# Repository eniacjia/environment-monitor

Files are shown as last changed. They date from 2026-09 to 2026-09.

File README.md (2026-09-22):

# DJIA Environmental Monitor

A compact environmental monitor built with an Arduino Uno, a 2.4-inch
MCUFRIEND TFT touchscreen shield, a BME280 sensor, and a DHT11 humidity module.
The device displays temperature and atmospheric pressure as large live readings
or rolling one-hour, eight-hour, and 24-hour charts, with live humidity.

> Local climate at a glance

Built by **DJIA using Codex**. The startup page generates `BUILD# YYYYMMDD`
automatically from the latest firmware compilation date.

## Features

- 2.4-inch 240 x 320 colour touchscreen
- BME280 temperature and pressure readings every 10 seconds
- DHT11 relative-humidity readings every 10 seconds
- Independent display mode for temperature, pressure, and humidity:
  - large current value
  - one-hour chart
  - eight-hour chart
  - 24-hour chart
- Automatic vertical chart scaling
- Touch the centre target to rotate the screen 90 degrees clockwise
- Portrait and landscape layouts
- Three-section dashboard: temperature, pressure, and humidity
- Ten-second branded startup page with large, centred title, tagline, build
  number, and attribution

## Project contents

| Path | Purpose |
|---|---|
| `firmware/EnvironmentMonitor/EnvironmentMonitor.ino` | Arduino source code |
| `firmware/release/` | Compiled Uno firmware files |
| `hardware/HARDWARE.md` | Wiring, pin use, and bill of materials |
| `docs/USER_GUIDE.md` | Operating instructions |
| `docs/FIRMWARE.md` | Firmware design and build instructions |
| `docs/TROUBLESHOOTING.md` | Diagnostic guidance |

## Quick start

1. Keep the TFT shield mounted on the Arduino Uno.
2. Keep the shield's microSD slot empty.
3. Connect BME280 `SDA` to `D11` and `SCL` to `D13`.
4. Connect BME280 power to `3.3V` and ground to `GND`.
5. Connect DHT11 `DATA` to `A5`, power to `5V`, and ground to `GND`.
6. Upload the sketch for an `arduino:avr:uno` target.
7. After startup, tap any measurement section to change its mode.

See [hardware/HARDWARE.md](hardware/HARDWARE.md) before connecting power.

## Important limitations

- Chart data currently resides in RAM and is lost after reset or power failure.
- The microSD interface cannot be used because `D11` and `D13` are repurposed
  for software I2C.
- The TFT backlight is wired directly to power on this shield. Software
  brightness control requires a transistor/MOSFET hardware modification.

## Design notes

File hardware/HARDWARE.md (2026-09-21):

# Hardware configuration

## Bill of materials

- Arduino Uno or fully compatible ATmega328P board
- 2.4-inch MCUFRIEND-style TFT LCD shield with resistive touchscreen
- BME280 breakout module
- DHT11 humidity module
- Seven jumper wires
- USB cable or suitable regulated Uno power supply

## Detected hardware

| Component | Detected/configured value |
|---|---|
| Arduino | Arduino Uno, ATmega328P |
| TFT controller | ILI9341, ID `0x9341` |
| TFT resolution | 240 x 320 pixels |
| Touch technology | Four-wire, single-touch resistive |
| Environmental sensor | BME280, chip ID `0x60` |
| Supported sensor addresses | `0x76` and `0x77` |
| Humidity sensor | DHT11 on `A5` |

## BME280 wiring

The Uno hardware I2C pins cannot be used because the shield uses `A4` for LCD
reset. The firmware therefore implements software I2C.

| BME280 pin | Arduino Uno pin | Notes |
|---|---|---|
| `VIN` or `VCC` | `3.3V` | Safest supply for the sensor |
| `GND` | `GND` | Common ground |
| `SDA` or `SDI` | `D11` | Software-I2C data |
| `SCL` or `SCK` | `D13` | Software-I2C clock |

Leave `CS` and `SDO` unconnected for this configuration. Some breakout boards
require `CS` pulled high to select I2C mode; use the breakout manufacturer's
instructions if it is not already pulled up.

## DHT11 wiring

| DHT11 pin | Arduino Uno pin | Notes |
|---|---|---|
| `VCC` or `+` | `5V` | Most three-pin DHT11 modules support 3.3-5 V |
| `DATA`, `S`, or `OUT` | `A5` | Used as digital pin 19 |
| `GND` or `-` | `GND` | Common ground |

Three-pin modules normally contain the required pull-up resistor. For a bare
four-pin DHT11, add a 4.7-10 kOhm resistor between `DATA` and `VCC`.

## TFT and touchscreen pin use

| Pins | Function |
|---|---|
| `D2-D9` | TFT parallel data bus; `D8-D9` are shared with touch |
| `A0-A4` | TFT control; `A2-A3` are shared with touch |
| `D10-D13` | Normally connected to the microSD slot |
| `D0-D1` | USB serial and sketch upload |
| `A5` | DHT11 single-wire data |

Because the sensor uses `D11` and `D13`, do not insert a microSD card while this
firmware is running.

## Measured touchscreen calibration

```cpp
const int XP = 8, XM = A2, YP = A3, YM = 9;
const int TS_LEFT = 125, TS_RT = 903;
const int TS_TOP = 129, TS_BOT = 878;
```

These values were measured for the specific shield used during development.
Recalibrate if a replacement shield has inaccurate or reversed touch input.

## Power notes

- Start with the BME280 powered from the Uno's `3.3V` output.
- The bare BME280 chip is not 5 V tolerant.
- A breakout labelled `VIN` may include a 5 V regulator and level shifting, but
  this must be confirmed from that module's documentation or schematic.
- Do not power the TFT backlight directly from a GPIO pin.

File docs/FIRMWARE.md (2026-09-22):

# Firmware notes

## Target

- Board FQBN: `arduino:avr:uno`
- MCU: ATmega328P
- Serial upload port used during development: `COM13`
- TFT controller: ILI9341 (`0x9341`)
- BME280 chip ID: `0x60`
- DHT11 data pin: `A5` (digital pin 19)

## Arduino libraries

Install these libraries through Arduino Library Manager:

- `MCUFRIEND_kbv` 3.0.0 or compatible
- `Adafruit GFX Library`
- `TouchScreen`

The sketch contains its own small software-I2C/BME280 driver and DHT11 protocol
reader. Adafruit BME280, BMP280, and DHT libraries are not required.

## Build with Arduino CLI

```powershell
arduino-cli compile --fqbn arduino:avr:uno firmware/EnvironmentMonitor
arduino-cli upload -p COM13 --fqbn arduino:avr:uno firmware/EnvironmentMonitor
```

Change `COM13` if the Uno appears on another port.

## Architecture

- `beginBMP280()` probes `0x76` and `0x77`, verifies BME280 ID `0x60`, loads
  temperature/pressure calibration coefficients, and configures normal mode.
- `readBMP280()` reads and compensates raw temperature and pressure values.
- `readDHT11()` performs the timed single-wire transaction, validates its
  checksum, and reports relative humidity.
- Software I2C uses open-drain-style pin switching on `D11/D13`.
- `collectHistory()` creates temperature and pressure averages, while
  `collectHumidityHistory()` creates equivalent DHT11 humidity averages. Each
  produces one-minute, eight-minute, and 24-minute history points from
  ten-second measurements.
- `drawPanel()` renders dynamically scaled history charts.
- `drawCurrentPanel()` renders centred, overprinted bold-style current values.
- `drawCurrentPanel()` also renders the dedicated light-green humidity section.
- `printBuildNumber()` converts the compiler-provided `__DATE__` value into the
  startup identifier `BUILD# YYYYMMDD` on every compile.
- `readTouch()` maps the measured resistive panel calibration for all four
  display rotations.

## RAM strategy

The Uno has only 2 KB of SRAM. Nine arrays of 60 signed 16-bit values retain
temperature, pressure, and humidity data for the one-hour, eight-hour, and
24-hour views. Values are stored in tenths of their displayed units. This
avoids storing thousands of individual ten-second samples.

## Persistence status

History is currently volatile. A future EEPROM implementation should use a
circular record layout, sequence counters, and checksums. Avoid rewriting a
single metadata byte every minute because ATmega328P EEPROM endurance is rated
at approximately 100,000 write/erase cycles per cell.

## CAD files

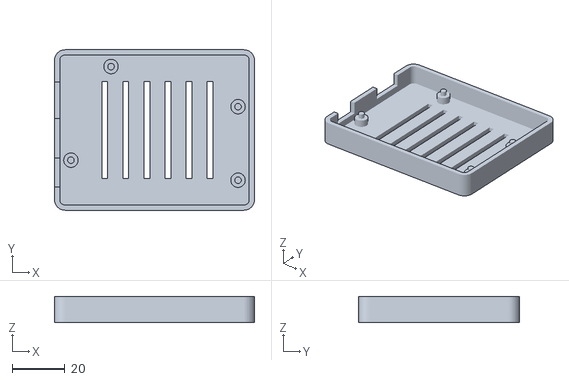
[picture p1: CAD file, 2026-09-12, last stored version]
enclosure/uno_24_tft_base.stl
76.0 x 61.0 x 10.0

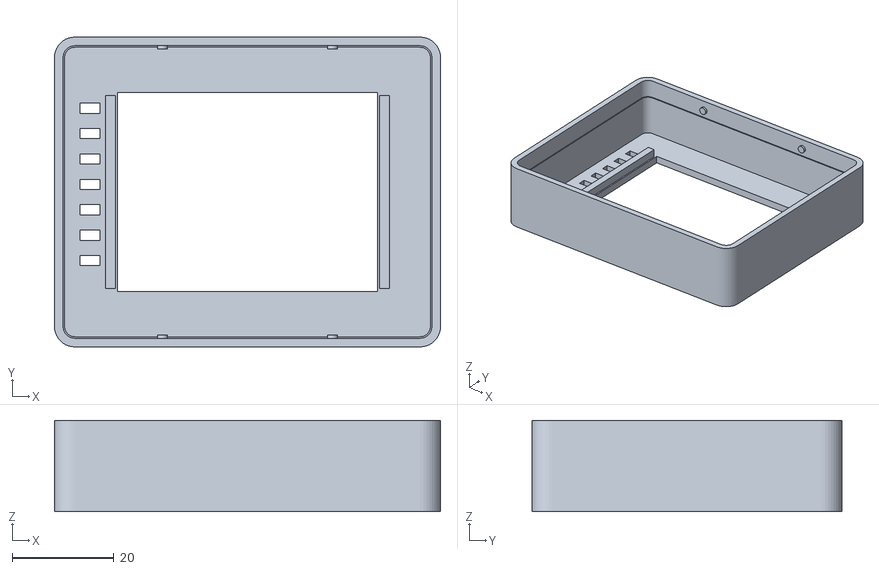
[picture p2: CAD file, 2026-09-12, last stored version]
enclosure/uno_24_tft_lid.stl
76.0 x 61.0 x 18.0

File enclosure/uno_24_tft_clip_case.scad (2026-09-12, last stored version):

/*
  Clip-on enclosure for Arduino Uno + common 2.4-inch MCUFRIEND TFT shield
  Designed for FDM printing. Units: millimetres.

  part = "print"     base and lid arranged for printing
  part = "base"      base only
  part = "lid"       lid only, bezel face down
  part = "assembly"  assembled preview
*/

$fn = 40;
part = "print";

// ---- Fit parameters: measure your particular shield before final printing ----
case_x = 76.0;
case_y = 61.0;
wall = 2.0;
corner_r = 4.0;
floor_t = 2.0;
base_h = 15.0;
lid_h = 18.0;
overlap = 5.0;
fit = 0.30;                 // per-side sliding clearance

uno_x = 68.6;
uno_y = 53.4;
board_x0 = (case_x - uno_x) / 2;
board_y0 = (case_y - uno_y) / 2;
standoff_h = 3.0;
standoff_od = 5.5;
standoff_pin = 2.5;

// Typical visible area for a 2.4-inch 240x320 module.
screen_x = 50.0;
screen_y = 38.0;
screen_center_x = case_x / 2;
screen_center_y = case_y / 2;
screen_clearance = 0.6;

// Connector locations measured from the lower-left outside corner.
usb_center_y = board_y0 + 38.0;
power_center_y = board_y0 + 10.5;

// Standard Uno mounting holes relative to the board lower-left corner.
uno_holes = [
  [2.54, 15.24],
  [17.78, 50.80],
  [66.04, 7.62],
  [66.04, 35.56]
];

module rounded_box(x, y, z, r) {
  linear_extrude(height=z)
    hull()
      for (px=[r, x-r], py=[r, y-r])
        translate([px, py]) circle(r=r);
}

module base_shell() {
  difference() {
    union() {
      rounded_box(case_x, case_y, base_h-overlap, corner_r);
      translate([wall, wall, base_h-overlap-0.2])
        rounded_box(case_x-2*wall, case_y-2*wall, overlap+0.2, corner_r-wall);
    }

    // Main electronics cavity.
    translate([wall, wall, floor_t])
      rounded_box(case_x-2*wall, case_y-2*wall, base_h+1, corner_r-wall);

    // USB type-B opening.
    translate([-1, usb_center_y-7.0, 5.0])
      cube([wall+3, 14.0, 12.0]);

    // DC barrel connector opening.
    translate([-1, power_center_y-5.5, 5.0])
      cube([wall+3, 11.0, 11.0]);

    // Snap pockets in the stepped rim.
    for (x=[case_x*0.28, case_x*0.72]) {
      translate([x-4, wall-1, base_h-3.2]) cube([8, wall+2, 2.0]);
      translate([x-4, case_y-wall-1, base_h-3.2]) cube([8, wall+2, 2.0]);
    }

    // Bottom ventilation.
    for (x=[18:8:58])
      translate([x, 12, -1]) cube([2.2, 37, floor_t+2]);
  }

  // Push-fit board supports. Pins can be clipped off for screw mounting.
  for (h=uno_holes)
    translate([board_x0+h[0], board_y0+h[1], floor_t-0.2]) {
      cylinder(h=standoff_h+0.2, d=standoff_od);
      cylinder(h=standoff_h+2.2, d=standoff_pin);
    }
}

module lid_shell() {
  difference() {
    rounded_box(case_x, case_y, lid_h, corner_r);

    // Open lower cavity; retain a 2 mm bezel roof.
    translate([wall, wall, -1])
      rounded_box(case_x-2*wall, case_y-2*wall,
                  lid_h-wall+1, corner_r-wall);

    // Clearance over the base's stepped rim.
    translate([wall-fit, wall-fit, -1])
      rounded_box(case_x-2*(wall-fit), case_y-2*(wall-fit),
                  overlap+1, corner_r-wall+fit);

    // Touchscreen opening.
    translate([screen_center_x-screen_x/2-screen_clearance,
               screen_center_y-screen_y/2-screen_clearance, lid_h-wall-1])
      cube([screen_x+2*screen_clearance,
            screen_y+2*screen_clearance, wall+2]);

    // Sensor airflow slots beside the screen.
    for (y=[16:5:46])
      translate([case_x-9, y, lid_h-wall-1])
        cube([4.0, 2.0, wall+2]);
  }

  // Four internal snap bumps. Chamfer-like cylinders ease assembly.
  for (x=[case_x*0.28, case_x*0.72]) {
    translate([x, wall+0.3, 2.8]) rotate([90,0,0]) cylinder(h=1.2, d=2.0);
    translate([x, case_y-wall-0.3, 2.8]) rotate([-90,0,0]) cylinder(h=1.2, d=2.0);
  }

  // Bezel ribs prevent the TFT PCB from rattling without touching the glass.
  for (x=[screen_center_x-screen_x/2-2.0,
          screen_center_x+screen_x/2+2.0])
    translate([x-1, screen_center_y-screen_y/2, lid_h-4.2])
      cube([2, screen_y, 2.4]);
}

module printable_lid() {
  // Flip so the flat bezel face is on the print bed; supports normally unnecessary.
  translate([case_x, 0, lid_h]) rotate([0,180,0]) lid_shell();
}

if (part == "base") {
  base_shell();
} else if (part == "lid") {
  printable_lid();
} else if (part == "assembly") {
  color("DimGray") base_shell();
  color("SlateGray", 0.85) translate([0,0,base_h-overlap]) lid_shell();
} else {
  base_shell();
  translate([case_x+10, 0, 0]) printable_lid();
}

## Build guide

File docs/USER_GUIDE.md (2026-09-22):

# User guide

## Startup

After power-on or reset, the display shows the startup page for ten seconds:

- Environmental Monitor
- Local climate at a glance
- `BUILD# YYYYMMDD`, generated automatically from the firmware compile date
- Built by DJIA using Codex

All startup text uses a large, centred layout for easier reading.

The monitor then detects the BME280 at address `0x76` or `0x77` and opens the
dashboard.

## Display sections

The screen is divided into three equal sections:

1. **TEMPERATURE** in yellow
2. **PRESSURE** in cyan
3. **HUMIDITY** in light green

Measurements update every ten seconds. Each of the three sections has four
independent selectable modes: current value, 1 hour, 8 hours, and 24 hours.

Tap any section to cycle it independently through four modes:

1. Large, centred current value
2. Rolling one-hour chart
3. Rolling eight-hour chart
4. Rolling 24-hour chart

The unit appears on the label line in the same colour as the reading.

## Rotation

A small two-ring target is drawn at the centre of the screen. Tap the target to
rotate the display 90 degrees clockwise. Four taps return it to the original
orientation. Touch coordinates and panel layouts adjust to each orientation.

## Charts

- Sensor acquisition interval: 10 seconds
- One-hour chart: 60 one-minute averages
- Eight-hour chart: 60 eight-minute averages
- 24-hour chart: 60 24-minute averages
- Vertical axis: automatically padded and rescaled
- New readings enter from the right side

The graph labels are `1 HOUR`, `8 HOUR`, and `24 HOUR`. It takes the full
selected period to fill each chart. History starts again after every restart
because persistence has not yet been enabled.

## Sensor error screen

If `BME280 not found` appears, verify:

- `SDA` is connected to `D11`
- `SCL` is connected to `D13`
- sensor power is connected to `3.3V`
- grounds are connected
- the microSD slot is empty

If the humidity section shows `--`, verify the DHT11 data wire is connected
to `A5`, check its power and ground, and confirm that a bare sensor has a data
pull-up resistor.

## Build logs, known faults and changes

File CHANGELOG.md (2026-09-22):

# Changelog

## 2026-09-21 — humidity history

- Added independent 1-hour, 8-hour, and 24-hour humidity charts.
- Added four-mode touch cycling to the humidity section.
- Added minute, eight-minute, and 24-minute DHT11 averaging buffers.

## 2026-09-21 — startup layout

- Centred the Environmental Monitor title.
- Enlarged and centred the tagline, automatic build number, and attribution.

## 2026-09-21 — three-section UI

- Replaced the humidity badge with a dedicated light-green humidity section.
- Split the adaptive dashboard into temperature, pressure, and humidity thirds.
- Made the startup build identifier compile automatically as `BUILD# YYYYMMDD`.

## 2026-09-21

- Added DHT11 relative-humidity measurement on `A5`.
- Added live DHT11 humidity display to the dashboard.
- Added a compact built-in DHT11 reader with checksum validation.
- Updated hardware, user, firmware, and troubleshooting documentation.

## 2026-09-13

- Added independent eight-hour temperature and pressure charts.
- Expanded each panel to four modes: current, 1 hour, 8 hours, and 24 hours.
- Simplified graph labels to `1 HOUR`, `8 HOUR`, and `24 HOUR`.
- Removed the experimental 3D enclosure models from the project.

## 2026-09-11

- Detected ILI9341 TFT controller (`0x9341`).
- Calibrated resistive touchscreen.
- Added BME280 temperature and pressure acquisition over software I2C.
- Added independent current, one-hour, and 24-hour display modes.
- Added automatic chart scaling and ten-second refresh.
- Added four-orientation touch rotation control.
- Added branded ten-second startup page.

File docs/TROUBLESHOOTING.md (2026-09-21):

# Troubleshooting

## LCD is blank after connecting the sensor

Do not connect the sensor to the Uno's normal `A4/A5` I2C pins. This TFT shield
uses `A4` as its reset line, so hardware-I2C traffic can reset or disrupt the
display. Use `D11` for SDA and `D13` for SCL with this firmware.

## BME280 not found

1. Remove any microSD card.
2. Check `SDA -> D11` and `SCL -> D13`.
3. Check `3.3V` and `GND`.
4. Confirm the chip is a BME280. The firmware expects chip ID `0x60`.
5. Check whether the breakout requires `CS` pulled high for I2C operation.
6. Restart the Uno after correcting the wiring.

## Touch does not respond accurately

The installed calibration is specific to the development shield. Run the
`MCUFRIEND_kbv/TouchScreen_Calibr_native` example, touch every target, and copy
the resulting pin and calibration constants into the sketch.

## Humidity shows `--%`

- Connect DHT11 data to `A5`, not to the BME280 software-I2C pins.
- Verify DHT11 power and common ground.
- A bare four-pin sensor needs a 4.7-10 kOhm pull-up from data to VCC.
- DHT11 sensors should not be read more frequently than once per second; this
  firmware reads every ten seconds.

## Upload reports “programmer is not responding”

- Close Serial Monitor and any application using the COM port.
- Disconnect the sensor temporarily and retry.
- Verify the selected board is Arduino Uno and select the detected COM port.
- Press Reset immediately before retrying.
- Try another known-good USB data cable.

## Display is too bright

This shield normally powers its backlight directly. Software dimming is not
available without modifying the backlight circuit. Use a transistor or MOSFET
controlled by PWM; never power the backlight directly from an Uno GPIO pin.

## Chart history disappears

This is expected in the current release. History is stored in SRAM and resets
after power loss or reset. EEPROM persistence is documented as a future option
in `FIRMWARE.md`.

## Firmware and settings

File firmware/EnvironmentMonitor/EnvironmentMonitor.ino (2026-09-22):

#include <Adafruit_GFX.h>
#include <MCUFRIEND_kbv.h>
#include <TouchScreen.h>

MCUFRIEND_kbv tft;

#define BLACK 0x0000
#define WHITE 0xFFFF
#define CYAN 0x07FF
#define YELLOW 0xFFE0
#define RED 0xF800
#define GREEN 0x07E0
#define LIGHTGREEN 0x87F0
#define DKGREY 0x2104

const uint8_t SDA_PIN = 11;
const uint8_t SCL_PIN = 13;
const uint8_t DHT_PIN = A5;
uint8_t sensorAddress = 0;

const int XP = 8, XM = A2, YP = A3, YM = 9;
const int TS_LEFT = 125, TS_RT = 903, TS_TOP = 129, TS_BOT = 878;
#define MINPRESSURE 200
#define MAXPRESSURE 1000
TouchScreen ts(XP, YP, XM, YM, 300);

uint16_t dig_T1, dig_P1;
int16_t dig_T2, dig_T3, dig_P2, dig_P3, dig_P4;
int16_t dig_P5, dig_P6, dig_P7, dig_P8, dig_P9;
int32_t tFine;

const uint8_t HISTORY_SIZE = 60;
int16_t temp1h[HISTORY_SIZE], pressure1h[HISTORY_SIZE];
int16_t temp8h[HISTORY_SIZE], pressure8h[HISTORY_SIZE];
int16_t temp24h[HISTORY_SIZE], pressure24h[HISTORY_SIZE];
int16_t humidity1h[HISTORY_SIZE], humidity8h[HISTORY_SIZE];
int16_t humidity24h[HISTORY_SIZE];
uint8_t count1h = 0, count8h = 0, count24h = 0;
uint8_t humidityCount1h = 0, humidityCount8h = 0, humidityCount24h = 0;
uint8_t samples1h = 0, samples8h = 0, samples24h = 0;
uint8_t humiditySamples1h = 0, humiditySamples8h = 0, humiditySamples24h = 0;
int32_t tempSum1h = 0, pressureSum1h = 0;
int32_t tempSum8h = 0, pressureSum8h = 0;
int32_t tempSum24h = 0, pressureSum24h = 0;
int32_t humiditySum1h = 0, humiditySum8h = 0, humiditySum24h = 0;
// Display modes: 0=current, 1=one hour, 2=eight hours, 3=24 hours.
uint8_t tempMode = 0, pressureMode = 0, humidityMode = 0;
uint8_t displayRotation = 0;
unsigned long lastReadingMs = 0;
float currentTemp = 0;
float currentPressure = 0;
float currentHumidity = NAN;
bool sensorFound = false;

bool waitForPinState(uint8_t state, unsigned long timeoutUs) {
  unsigned long started = micros();
  while (digitalRead(DHT_PIN) != state) {
    if (micros() - started > timeoutUs) return false;
  }
  return true;
}

bool readDHT11(float &humidity) {
  uint8_t data[5] = {0, 0, 0, 0, 0};
  pinMode(DHT_PIN, OUTPUT);
  digitalWrite(DHT_PIN, LOW);
  delay(20);
  digitalWrite(DHT_PIN, HIGH);
  delayMicroseconds(30);
  pinMode(DHT_PIN, INPUT_PULLUP);

  if (!waitForPinState(LOW, 120) || !waitForPinState(HIGH, 120) ||
      !waitForPinState(LOW, 120)) {
    return false;
  }
  for (uint8_t bit = 0; bit < 40; bit++) {
    if (!waitForPinState(HIGH, 100)) return false;
    unsigned long highStarted = micros();
    if (!waitForPinState(LOW, 120)) return false;
    data[bit / 8] <<= 1;
    if (micros() - highStarted > 40) data[bit / 8] |= 1;
  }

  uint8_t checksum = data[0] + data[1] + data[2] + data[3];
  if (checksum != data[4]) return false;
  humidity = data[0] + data[1] * 0.1F;
  return humidity >= 0.0F && humidity <= 100.0F;
}

void lineLow(uint8_t pin) { pinMode(pin, OUTPUT); digitalWrite(pin, LOW); }
void lineHigh(uint8_t pin) { pinMode(pin, INPUT_PULLUP); }
void i2cDelay() { delayMicroseconds(5); }

void i2cStart() {
  lineHigh(SDA_PIN); lineHigh(SCL_PIN); i2cDelay();
  lineLow(SDA_PIN); i2cDelay(); lineLow(SCL_PIN);
}

void i2cStop() {
  lineLow(SDA_PIN); lineHigh(SCL_PIN); i2cDelay();
  lineHigh(SDA_PIN); i2cDelay();
}

bool i2cWrite(uint8_t value) {
  for (uint8_t i = 0; i < 8; i++) {
    if (value & 0x80) lineHigh(SDA_PIN); else lineLow(SDA_PIN);
    i2cDelay(); lineHigh(SCL_PIN); i2cDelay(); lineLow(SCL_PIN);
    value <<= 1;
  }
  lineHigh(SDA_PIN); i2cDelay(); lineHigh(SCL_PIN); i2cDelay();
  bool ack = !digitalRead(SDA_PIN);
  lineLow(SCL_PIN);
  return ack;
}

uint8_t i2cRead(bool ack) {
  uint8_t value = 0;
  lineHigh(SDA_PIN);
  for (uint8_t i = 0; i < 8; i++) {
    value <<= 1; lineHigh(SCL_PIN); i2cDelay();
    if (digitalRead(SDA_PIN)) value |= 1;
    lineLow(SCL_PIN); i2cDelay();
  }
  if (ack) lineLow(SDA_PIN); else lineHigh(SDA_PIN);
  lineHigh(SCL_PIN); i2cDelay(); lineLow(SCL_PIN); lineHigh(SDA_PIN);
  return value;
}

bool writeReg(uint8_t reg, uint8_t value) {
  i2cStart();
  bool ok = i2cWrite(sensorAddress << 1) && i2cWrite(reg) && i2cWrite(value);
  i2cStop();
  return ok;
}

bool readRegs(uint8_t reg, uint8_t *data, uint8_t length) {
  i2cStart();
  if (!i2cWrite(sensorAddress << 1) || !i2cWrite(reg)) { i2cStop(); return false; }
  i2cStart();
  if (!i2cWrite((sensorAddress << 1) | 1)) { i2cStop(); return false; }
  for (uint8_t i = 0; i < length; i++) data[i] = i2cRead(i + 1 < length);
  i2cStop();
  return true;
}

uint16_t u16le(const uint8_t *p) { return uint16_t(p[0]) | (uint16_t(p[1]) << 8); }
int16_t s16le(const uint8_t *p) { return (int16_t)u16le(p); }

bool beginBMP280() {
  lineHigh(SDA_PIN); lineHigh(SCL_PIN);
  uint8_t id = 0;
  const uint8_t addresses[] = {0x76, 0x77};
  for (uint8_t i = 0; i < 2; i++) {
    sensorAddress = addresses[i];
    // 0x60 = BME280.  Read only its temperature and pressure channels.
    if (readRegs(0xD0, &id, 1) && id == 0x60) break;
    if (i == 1) return false;
  }
  uint8_t c[24];
  if (!readRegs(0x88, c, 24)) return false;
  dig_T1=u16le(c); dig_T2=s16le(c+2); dig_T3=s16le(c+4);
  dig_P1=u16le(c+6); dig_P2=s16le(c+8); dig_P3=s16le(c+10);
  dig_P4=s16le(c+12); dig_P5=s16le(c+14); dig_P6=s16le(c+16);
  dig_P7=s16le(c+18); dig_P8=s16le(c+20); dig_P9=s16le(c+22);
  writeReg(0xF4, 0x27);
  writeReg(0xF5, 0xA0);
  return true;
}

bool readBMP280(float &temperature, float &pressure) {
  uint8_t d[6];
  if (!readRegs(0xF7, d, 6)) return false;
  int32_t adcP=(int32_t(d[0])<<12)|(int32_t(d[1])<<4)|(d[2]>>4);
  int32_t adcT=(int32_t(d[3])<<12)|(int32_t(d[4])<<4)|(d[5]>>4);
  int32_t v1=((((adcT>>3)-((int32_t)dig_T1<<1)))*dig_T2)>>11;
  int32_t v2=(((((adcT>>4)-(int32_t)dig_T1)*((adcT>>4)-(int32_t)dig_T1))>>12)*dig_T3)>>14;
  tFine=v1+v2;
  temperature=((tFine*5+128)>>8)/100.0F;
  int64_t p1=(int64_t)tFine-128000;
  int64_t p2=p1*p1*dig_P6;
  p2+=(p1*dig_P5)<<17;
  p2+=((int64_t)dig_P4)<<35;
  p1=((p1*p1*dig_P3)>>8)+((p1*dig_P2)<<12);
  p1=(((int64_t)1<<47)+p1)*dig_P1>>33;
  if (p1 == 0) return false;
  int64_t p=1048576-adcP;
  p=(((p<<31)-p2)*3125)/p1;
  p1=(dig_P9*(p>>13)*(p>>13))>>25;
  p2=(dig_P8*p)>>19;
  p=((p+p1+p2)>>8)+((int64_t)dig_P7<<4);
  pressure=(p/256.0F)/100.0F;
  return true;
}

void pushPair(int16_t *temperatures, int16_t *pressures, uint8_t &count,
              int16_t temperature, int16_t pressure) {
  if (count < HISTORY_SIZE) {
    temperatures[count] = temperature;
    pressures[count] = pressure;
    count++;
  }
  else {
    memmove(temperatures, temperatures + 1, (HISTORY_SIZE - 1) * sizeof(int16_t));
    memmove(pressures, pressures + 1, (HISTORY_SIZE - 1) * sizeof(int16_t));
    temperatures[HISTORY_SIZE - 1] = temperature;
    pressures[HISTORY_SIZE - 1] = pressure;
  }
}

void pushSingle(int16_t *values, uint8_t &count, int16_t value) {
  if (count < HISTORY_SIZE) values[count++] = value;
  else {
    memmove(values, values + 1, (HISTORY_SIZE - 1) * sizeof(int16_t));
    values[HISTORY_SIZE - 1] = value;
  }
}

void collectHistory(float temperature, float pressure) {
  int16_t t = (int16_t)(temperature * 10.0F);
  int16_t p = (int16_t)(pressure * 10.0F);
  tempSum1h += t; pressureSum1h += p; samples1h++;
  tempSum8h += t; pressureSum8h += p; samples8h++;
  tempSum24h += t; pressureSum24h += p; samples24h++;
  if (samples1h == 6) {
    pushPair(temp1h, pressure1h, count1h,
             tempSum1h / samples1h, pressureSum1h / samples1h);
    tempSum1h = pressureSum1h = 0; samples1h = 0;
  }
  if (samples8h == 48) {
    pushPair(temp8h, pressure8h, count8h,
             tempSum8h / samples8h, pressureSum8h / samples8h);
    tempSum8h = pressureSum8h = 0; samples8h = 0;
  }
  if (samples24h == 144) {
    pushPair(temp24h, pressure24h, count24h,
             tempSum24h / samples24h, pressureSum24h / samples24h);
    tempSum24h = pressureSum24h = 0; samples24h = 0;
  }
}

void collectHumidityHistory(float humidity) {
  int16_t h = (int16_t)(humidity * 10.0F);
  humiditySum1h += h; humiditySamples1h++;
  humiditySum8h += h; humiditySamples8h++;
  humiditySum24h += h; humiditySamples24h++;
  if (humiditySamples1h == 6) {
    pushSingle(humidity1h, humidityCount1h, humiditySum1h / humiditySamples1h);
    humiditySum1h = 0; humiditySamples1h = 0;
  }
  if (humiditySamples8h == 48) {
    pushSingle(humidity8h, humidityCount8h, humiditySum8h / humiditySamples8h);
    humiditySum8h = 0; humiditySamples8h = 0;
  }
  if (humiditySamples24h == 144) {
    pushSingle(humidity24h, humidityCount24h, humiditySum24h / humiditySamples24h);
    humiditySum24h = 0; humiditySamples24h = 0;
  }
}

void drawPanel(uint8_t panel, const __FlashStringHelper *title, float current,
               const __FlashStringHelper *unit, int16_t *history, uint16_t color,
               int16_t minimumSpan, uint8_t count,
               const __FlashStringHelper *rangeLabel) {
  int16_t sectionHeight = tft.height() / 3;
  int16_t top = panel * sectionHeight;
  if (panel == 2) sectionHeight = tft.height() - top;
  int16_t chartTop = top + 30;
  int16_t chartBottom = top + sectionHeight - 7;
  int16_t chartLeft = 8;
  int16_t chartRight = tft.width() - 8;
  tft.fillRect(0, top, tft.width(), sectionHeight, BLACK);
  tft.drawRect(0, top, tft.width(), sectionHeight, WHITE);
  tft.setTextSize(1); tft.setTextColor(WHITE); tft.setCursor(8, top + 11);
  tft.print(title);
  tft.setTextSize(1); tft.setTextColor(color); tft.setCursor(92, top + 11);
  tft.print(current, 1); tft.print(unit);

  for (uint8_t i = 0; i <= 4; i++) {
    int16_t y = chartTop + (chartBottom - chartTop) * i / 4;
    tft.drawFastHLine(chartLeft, y, chartRight - chartLeft + 1, DKGREY);
  }
  for (uint8_t i = 0; i <= 6; i++) {
    int16_t x = chartLeft + (chartRight - chartLeft) * i / 6;
    tft.drawFastVLine(x, chartTop, chartBottom - chartTop + 1, DKGREY);
  }
  if (count == 0) return;

  int16_t low = history[0], high = history[0];
  for (uint8_t i = 1; i < count; i++) {
    if (history[i] < low) low = history[i];
    if (history[i] > high) high = history[i];
  }
  if (high - low < minimumSpan) {
    int16_t middle = (high + low) / 2;
    low = middle - minimumSpan / 2;
    high = low + minimumSpan;
  } else {
    int16_t pad = (high - low) / 8 + 1;
    low -= pad; high += pad;
  }

  int16_t previousX = chartRight - (count - 1) * (chartRight - chartLeft) / 59;
  int16_t previousY = map(history[0], low, high, chartBottom, chartTop);
  for (uint8_t i = 1; i < count; i++) {
    int16_t x = chartRight - (count - 1 - i) * (chartRight - chartLeft) / 59;
    int16_t y = map(history[i], low, high, chartBottom, chartTop);
    tft.drawLine(previousX, previousY, x, y, color);
    previousX = x; previousY = y;
  }
  tft.fillRect(previousX - 1, previousY - 1, 3, 3, color);

  tft.setTextSize(1); tft.setTextColor(WHITE);
  tft.setCursor(chartLeft + 2, chartTop + 2); tft.print(high / 10.0F, 1);
  tft.setCursor(chartLeft + 2, chartBottom - 9); tft.print(low / 10.0F, 1);
  tft.setCursor(chartRight - 45, chartBottom - 9);
  tft.print(rangeLabel);
}

void drawCurrentPanel(uint8_t panel, const __FlashStringHelper *title,
                      float current, const __FlashStringHelper *unit,
                      uint16_t color, uint8_t textSize) {
  int16_t sectionHeight = tft.height() / 3;
  int16_t top = panel * sectionHeight;
  if (panel == 2) sectionHeight = tft.height() - top;
  tft.fillRect(0, top, tft.width(), sectionHeight, BLACK);
  tft.drawRect(0, top, tft.width(), sectionHeight, WHITE);
  tft.setTextColor(WHITE); tft.setTextSize(2);
  tft.setCursor(8, top + 12); tft.print(title);
  tft.setTextColor(color); tft.setTextSize(2);
  tft.setCursor(tft.width() - (panel == 1 ? 48 : 30), top + 12);
  tft.print(unit);

  if (sectionHeight < 100 && textSize > 4) textSize = 4;
  else if (textSize > 5) textSize = 5;
  tft.setTextSize(textSize);
  bool valid = !isnan(current);
  uint8_t characters = valid ? (current >= 1000.0F ? 6 :
                       (current >= 100.0F ? 5 : (current >= 10.0F ? 4 : 3))) : 2;
  if (valid && current < 0.0F) characters++;
  int16_t valueX = (tft.width() - characters * 6 * textSize) / 2;
  int16_t valueY = top + 36 + (sectionHeight - 36 - 8 * textSize) / 2;
  tft.setTextColor(color);
  tft.setCursor(valueX, valueY);
  if (valid) tft.print(current, 1); else tft.print(F("--"));
  tft.setCursor(valueX + 1, valueY);
  if (valid) tft.print(current, 1); else tft.print(F("--"));
}

void drawDashboard() {
  if (tempMode == 0)
    drawCurrentPanel(0, F("TEMPERATURE"), currentTemp, F("C"), YELLOW, 6);
  else
    drawPanel(0, F("TEMPERATURE"), currentTemp, F("C"),
              tempMode == 1 ? temp1h : (tempMode == 2 ? temp8h : temp24h),
              YELLOW, 20,
              tempMode == 1 ? count1h : (tempMode == 2 ? count8h : count24h),
              tempMode == 1 ? F("1 HOUR") : (tempMode == 2 ? F("8 HOUR") : F("24 HOUR")));

  if (pressureMode == 0)
    drawCurrentPanel(1, F("PRESSURE"), currentPressure, F("hPa"), CYAN, 5);
  else
    drawPanel(1, F("PRESSURE"), currentPressure, F("hPa"),
              pressureMode == 1 ? pressure1h : (pressureMode == 2 ? pressure8h : pressure24h),
              CYAN, 50,
              pressureMode == 1 ? count1h : (pressureMode == 2 ? count8h : count24h),
              pressureMode == 1 ? F("1 HOUR") : (pressureMode == 2 ? F("8 HOUR") : F("24 HOUR")));

  if (humidityMode == 0)
    drawCurrentPanel(2, F("HUMIDITY"), currentHumidity, F("%"), LIGHTGREEN, 5);
  else
    drawPanel(2, F("HUMIDITY"), currentHumidity, F("%"),
              humidityMode == 1 ? humidity1h : (humidityMode == 2 ? humidity8h : humidity24h),
              LIGHTGREEN, 100,
              humidityMode == 1 ? humidityCount1h :
                (humidityMode == 2 ? humidityCount8h : humidityCount24h),
              humidityMode == 1 ? F("1 HOUR") :
                (humidityMode == 2 ? F("8 HOUR") : F("24 HOUR")));

  int16_t centerX = tft.width() / 2;
  int16_t centerY = tft.height() / 2;
  tft.fillRect(centerX - 8, centerY - 8, 17, 17, BLACK);
  tft.drawCircle(centerX, centerY, 7, WHITE);
  tft.drawCircle(centerX, centerY, 4, WHITE);
}

void printBuildNumber() {
  static const char months[] PROGMEM = "JanFebMarAprMayJunJulAugSepOctNovDec";
  uint8_t month = 1;
  for (uint8_t i = 0; i < 12; i++) {
    if (pgm_read_byte(months + i * 3) == __DATE__[0] &&
        pgm_read_byte(months + i * 3 + 1) == __DATE__[1] &&
        pgm_read_byte(months + i * 3 + 2) == __DATE__[2]) {
      month = i + 1;
      break;
    }
  }
  tft.print(F("BUILD# "));
  tft.print(__DATE__ + 7);
  if (month < 10) tft.print('0');
  tft.print(month);
  tft.write(__DATE__[4] == ' ' ? '0' : __DATE__[4]);
  tft.write(__DATE__[5]);
}

void showStartupPage() {
  tft.fillScreen(BLACK);
  tft.drawRect(8, 12, 224, 296, DKGREY);
  tft.setTextColor(YELLOW); tft.setTextSize(2);
  tft.setCursor(42, 45); tft.print(F("ENVIRONMENTAL"));
  tft.setCursor(78, 72); tft.print(F("MONITOR"));
  tft.drawFastHLine(30, 102, 180, CYAN);

  tft.setTextColor(WHITE); tft.setTextSize(2);
  tft.setCursor(42, 122); tft.print(F("Local climate"));
  tft.setCursor(54, 148); tft.print(F("at a glance"));

  tft.setTextColor(CYAN); tft.setTextSize(2);
  tft.setCursor(30, 190); printBuildNumber();

  tft.setTextColor(WHITE); tft.setTextSize(2);
  tft.setCursor(42, 232); tft.print(F("Built by DJIA"));
  tft.setCursor(54, 258); tft.print(F("using Codex"));
  delay(10000);
}

void showError() {
  tft.fillScreen(BLACK);
  tft.setTextColor(RED); tft.setTextSize(2); tft.setCursor(22, 80);
  tft.print(F("BME280 not found"));
  tft.setTextColor(WHITE); tft.setTextSize(1); tft.setCursor(15, 125);
  tft.print(F("SDA=D11  SCL=D13"));
  tft.setCursor(15, 145); tft.print(F("Check 3.3V and GND"));
}

bool readTouch(int16_t &x, int16_t &y) {
  TSPoint point = ts.getPoint();
  pinMode(YP, OUTPUT); pinMode(XM, OUTPUT);
  digitalWrite(YP, HIGH); digitalWrite(XM, HIGH);
  if (point.z <= MINPRESSURE || point.z >= MAXPRESSURE) return false;
  if (displayRotation == 0) {
    x = map(point.x, TS_LEFT, TS_RT, 0, tft.width());
    y = map(point.y, TS_TOP, TS_BOT, 0, tft.height());
  } else if (displayRotation == 1) {
    x = map(point.y, TS_TOP, TS_BOT, 0, tft.width());
    y = map(point.x, TS_RT, TS_LEFT, 0, tft.height());
  } else if (displayRotation == 2) {
    x = map(point.x, TS_RT, TS_LEFT, 0, tft.width());
    y = map(point.y, TS_BOT, TS_TOP, 0, tft.height());
  } else {
    x = map(point.y, TS_BOT, TS_TOP, 0, tft.width());
    y = map(point.x, TS_LEFT, TS_RT, 0, tft.height());
  }
  return true;
}

void setup() {
  uint16_t id = tft.readID();
  if (id == 0xD3D3) id = 0x9341;
  tft.begin(id); tft.setRotation(0); tft.fillScreen(BLACK);
  showStartupPage();
  sensorFound = beginBMP280();
  if (!sensorFound || !readBMP280(currentTemp, currentPressure)) {
    showError();
    return;
  }
  if (readDHT11(currentHumidity)) {
    int16_t initialHumidity = currentHumidity * 10.0F;
    pushSingle(humidity1h, humidityCount1h, initialHumidity);
    pushSingle(humidity8h, humidityCount8h, initialHumidity);
    pushSingle(humidity24h, humidityCount24h, initialHumidity);
  }
  pushPair(temp1h, pressure1h, count1h,
           currentTemp * 10.0F, currentPressure * 10.0F);
  pushPair(temp8h, pressure8h, count8h,
           currentTemp * 10.0F, currentPressure * 10.0F);
  pushPair(temp24h, pressure24h, count24h,
           currentTemp * 10.0F, currentPressure * 10.0F);
  lastReadingMs = millis();
  drawDashboard();
}

void loop() {
  static bool touchWasDown = false;
  int16_t touchX, touchY;
  bool touchDown = readTouch(touchX, touchY);
  if (sensorFound && touchDown && !touchWasDown) {
    int16_t centerX = tft.width() / 2;
    int16_t centerY = tft.height() / 2;
    if (abs(touchX - centerX) <= 16 && abs(touchY - centerY) <= 16) {
      displayRotation = (displayRotation + 1) % 4;
      tft.setRotation(displayRotation);
      tft.fillScreen(BLACK);
    } else {
      int16_t sectionHeight = tft.height() / 3;
      if (touchY < sectionHeight) tempMode = (tempMode + 1) % 4;
      else if (touchY < sectionHeight * 2) pressureMode = (pressureMode + 1) % 4;
      else humidityMode = (humidityMode + 1) % 4;
    }
    drawDashboard();
  }
  touchWasDown = touchDown;

  if (!sensorFound) {
    if (millis() - lastReadingMs >= 5000) {
      lastReadingMs = millis();
      sensorFound = beginBMP280();
      if (sensorFound && readBMP280(currentTemp, currentPressure)) {
        if (readDHT11(currentHumidity)) {
          int16_t initialHumidity = currentHumidity * 10.0F;
          pushSingle(humidity1h, humidityCount1h, initialHumidity);
          pushSingle(humidity8h, humidityCount8h, initialHumidity);
          pushSingle(humidity24h, humidityCount24h, initialHumidity);
        }
        pushPair(temp1h, pressure1h, count1h,
                 currentTemp * 10.0F, currentPressure * 10.0F);
        pushPair(temp8h, pressure8h, count8h,
                 currentTemp * 10.0F, currentPressure * 10.0F);
        pushPair(temp24h, pressure24h, count24h,
                 currentTemp * 10.0F, currentPressure * 10.0F);
        drawDashboard();
      }
    }
    return;
  }
  if (millis() - lastReadingMs >= 10000UL) {
    lastReadingMs = millis();
    if (!readBMP280(currentTemp, currentPressure)) {
      sensorFound = false; showError(); return;
    }
    if (readDHT11(currentHumidity)) collectHumidityHistory(currentHumidity);
    collectHistory(currentTemp, currentPressure);
    drawDashboard();
  }
}

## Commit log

2026-09-12 Add Arduino environmental monitor project
    [uno_24_tft_base.stl, uno_24_tft_clip_case.scad, uno_24_tft_lid.stl]
2026-09-14 Add 8-hour charts and remove enclosure models
    [uno_24_tft_base.stl, uno_24_tft_clip_case.scad, uno_24_tft_lid.stl]
